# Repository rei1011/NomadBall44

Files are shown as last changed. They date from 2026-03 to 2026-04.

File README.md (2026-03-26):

# NomadBall44

## ライセンス

本リポジトリのオリジナル部分は **GNU General Public License v3**（[LICENSE](LICENSE)）です。

## 第三者ソフトウェア・素材

キーボード設計にあたり、以下のオープンソース／クリエイティブ・コモンズの成果物を利用しています。帰属表示、MIT 全文、GPLv3 との関係、CC BY-SA の条項へのリンクは **[NOTICES](NOTICES)** にまとめています。上流ライセンスのコピーは **[third_party/](third_party/)** にも置いています。

| 名称 | 参照 |
|---|---|
| Salicylic-acid3 / KiCAD_FootPrint（MIT） | https://github.com/Salicylic-acid3/KiCAD_FootPrint |
| koktoh / BrownSugar_KBD_KiCad_Library（MIT） | https://github.com/koktoh/BrownSugar_KBD_KiCad_Library |
| kumamuk-git / roBa（GPL-3.0） | https://github.com/kumamuk-git/roBa |
| Seeed Studio / OPL_Kicad_Library（CC BY-SA 4.0） | https://github.com/Seeed-Studio/OPL_Kicad_Library |

Seeed OPL 由来の KiCad シンボル・フットプリントのファイル一覧、改変内容の説明、および派生ファイルを単体で再配布する際の表示の目安は、**[NOTICES](NOTICES)** のセクション 4 に記載しています。

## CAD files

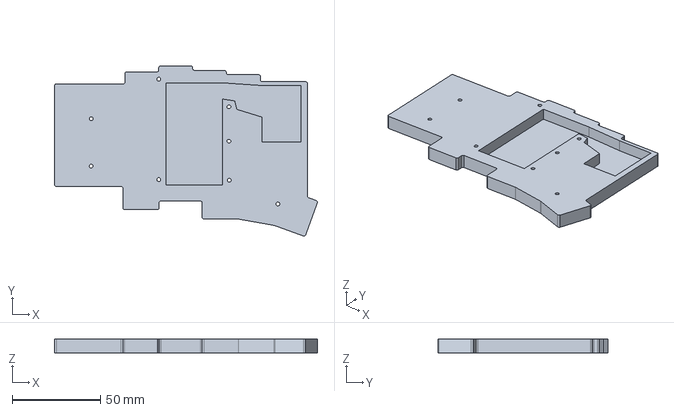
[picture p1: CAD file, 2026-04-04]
design_data/NomadBall44_L_Bottom_v2/freecad/NomadBall44_L_Bottom_v2.FCStd
149.0 x 96.5 x 7.70 mm

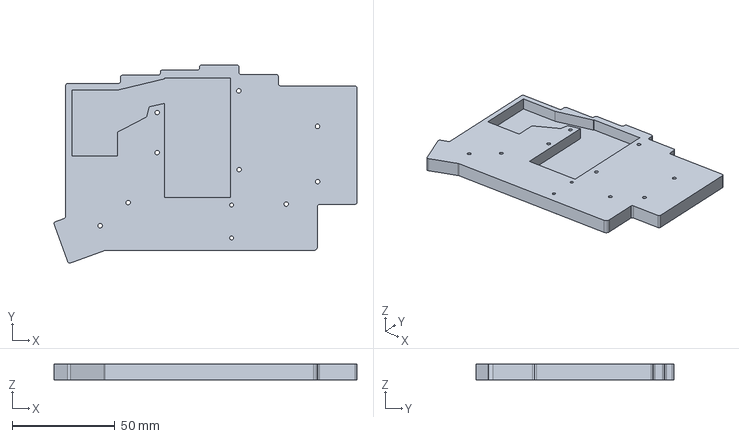
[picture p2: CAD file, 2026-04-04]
design_data/NomadBall44_R_Bottom_v2/freecad/NomadBall44_R_Bottom_v2.FCStd
147.4 x 96.5 x 7.70 mm

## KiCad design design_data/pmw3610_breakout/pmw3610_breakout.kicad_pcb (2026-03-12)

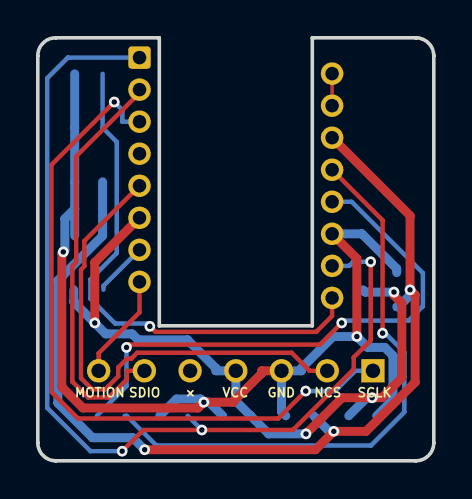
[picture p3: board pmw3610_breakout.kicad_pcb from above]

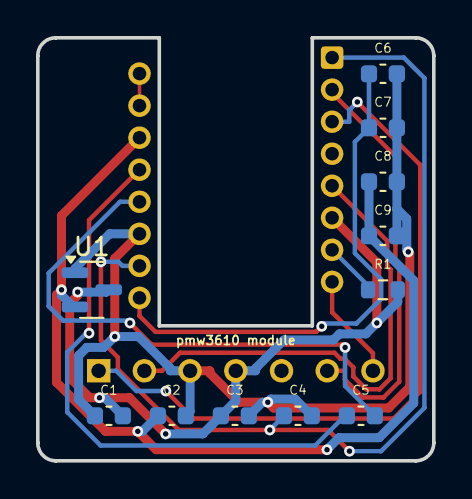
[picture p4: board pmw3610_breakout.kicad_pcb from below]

Board: 2 copper layers, 22.0 x 23.5 mm, 13 parts (11 on the bottom side), 13 nets.

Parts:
C1, C2: 1u; C_0603_1608Metric
C3, C5, C8: 100n; C_0603_1608Metric
C4, C7: 10n; C_0603_1608Metric
C6: 10u (X7R); C_0603_1608Metric
C9: 3.3u/25V; C_0603_1608Metric
J1: Conn_01x08; pmw3610_connector_b
R1: 10k; R_0603_1608Metric
U1: MCP1700T-1802E/TT; SOT-23
U2: PMW3610; PMW3610DM-SUDU 16Pin

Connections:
+1V9: C2.1, C8.1, C9.1, U1.2 (VO), U2.14 (VDD)
GND: C1.1, C2.2, C3.2, C4.2, C6.2, C7.2, C8.2, C9.2, J1.3, U1.1 (GND), U2.11 (GND)
MOTION: J1.7 (Pin_6), U2.8 (MOTION)
NCS: J1.2, U2.5 (NCS)
unnamed: C4.1, U2.1 (+VCSEL), U2.10 (PASS_T)
unnamed: U2.15 (XYLASER), U2.16 (-VCSEL)
unnamed: C5.1, U2.13 (CN)
unnamed: C5.2, U2.12 (CP)
unnamed: R1.1, U2.7 (NRESET)
unnamed: C6.1, C7.1, U2.9 (VCP)
SCLK: J1.1, U2.3 (SCLK)
SDIO: J1.6, U2.2 (SDIO)
VCC: C1.2, C3.1, J1.4, R1.2, U1.3 (VI), U2.6 (VDDIO)

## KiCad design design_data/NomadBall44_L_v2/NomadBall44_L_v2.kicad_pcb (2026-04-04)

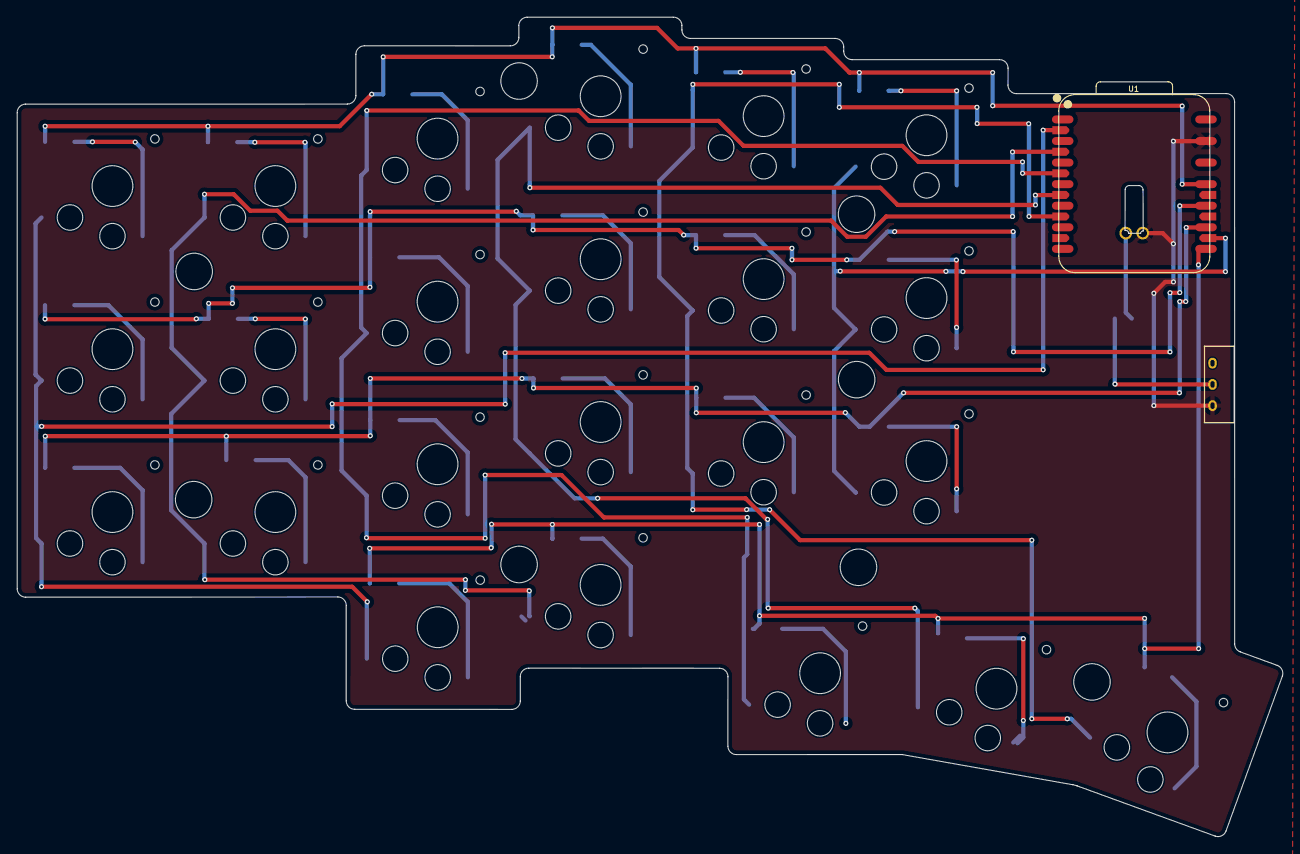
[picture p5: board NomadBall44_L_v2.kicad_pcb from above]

Board: 2 copper layers, 149.0 x 96.5 mm, 49 parts (1 on the bottom side), 36 nets.

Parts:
BT1: Battery_Cell; JST_S2B-PH-SM4-TB
D1, D2, D3, D4, D5, D6, D7, D8, D9, D10, D11, D12, D13, D14, D15, D16, D17, D18, D19, D20, D21, D22, D23: D; Diode_SMD
SW1, SW2, SW3, SW4, SW5, SW6, SW7, SW8, SW9, SW10, SW11, SW12, SW13, SW14, SW15, SW16, SW17, SW18, SW19, SW20, SW21, SW22, SW23: SW_Push; Choc_v2_Hotswap_1u
SW24: SW_SPDT; TGSW_MSK-12D19
U1: XIAO-nRF52840-Plus-SMD; XIAO-nRF52840-Plus-ver3

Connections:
Bat: BT1.1 (+), U1.32 (VBAT)
Col0: SW1.1, SW7.1, SW13.1, SW19.1, U1.15 (P0.15_D11_I2S_SD)
Col1: SW2.1, SW8.1, SW14.1, SW20.1, U1.16 (P0.19_D12_I2S_SCK)
Col2: SW3.1, SW9.1, SW15.1, SW21.1, U1.17 (P1.01_D13_I2S_WS)
Col3: SW4.1, SW10.1, SW16.1, SW22.1, U1.18 (P0.09_D14_NFC1_RX1)
Col4: SW5.1, SW11.1, SW17.1, SW23.1, U1.19 (P0.10_D15_NFC2_TX1)
Col5: SW6.1, SW12.1, SW18.1, U1.21 (P1.03_D17_SCK1)
GND: SW24.3 (C), U1.13 (GND), U1.33 (GND)
unnamed: BT1.2 (-), SW24.2 (B)
unnamed: D1.2 (A), SW1.2
unnamed: D2.2 (A), SW2.2
unnamed: D3.2 (A), SW3.2
unnamed: D4.2 (A), SW4.2
unnamed: D5.2 (A), SW5.2
unnamed: D6.2 (A), SW6.2
unnamed: D7.2 (A), SW7.2
unnamed: D8.2 (A), SW8.2
unnamed: D9.2 (A), SW9.2
unnamed: D10.2 (A), SW10.2
unnamed: D11.2 (A), SW11.2
unnamed: D12.2 (A), SW12.2
unnamed: D13.2 (A), SW13.2
unnamed: D14.2 (A), SW14.2
unnamed: D15.2 (A), SW15.2
unnamed: D16.2 (A), SW16.2
unnamed: D17.2 (A), SW17.2
unnamed: D18.2 (A), SW18.2
unnamed: D19.2 (A), SW19.2
unnamed: D20.2 (A), SW20.2
unnamed: D21.2 (A), SW21.2
unnamed: D22.2 (A), SW22.2
unnamed: D23.2 (A), SW23.2
Row0: D1.1 (K), D2.1 (K), D3.1 (K), D4.1 (K), D5.1 (K), D6.1 (K), U1.11 (P1.15_D10_MOSI)
Row1: D7.1 (K), D8.1 (K), D9.1 (K), D10.1 (K), D11.1 (K), D12.1 (K), U1.10 (P1.14_D9_MISO)
Row2: D13.1 (K), D14.1 (K), D15.1 (K), D16.1 (K), D17.1 (K), D18.1 (K), U1.9 (P1.13_D8_SCK)
Row3: D19.1 (K), D20.1 (K), D21.1 (K), D22.1 (K), D23.1 (K), U1.8 (P1.12_D7_RX)

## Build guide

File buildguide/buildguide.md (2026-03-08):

# ダイオードはんだ付け
- 部品
  - ダイオード
- 手順
  - PCB基板裏面へダイオードを取り付ける

# キーソケットはんだ付け
- 部品
  - キースケット
- 手順
  - PCB基板裏面へキーソケットを取り付ける
    - 親指キーはchoc v1、choc v2を取り付ける

# マイコン関連のはんだ付け
- 部品
  - マイコン
  - PHコネクタ
  - スライドスイッチ
- 手順
  - PCB基板表面へマイコンを取り付ける
    - バッテリー用ピンは裏面からはんだ付けを行う
  - PCB基板裏面へPHコネクタを取り付ける
  - PCB基板表面へ水平スライドスイッチを取り付ける

# ロータリーエンコーダーはんだ付け
- 部品
  - ロータリーエンコーダー
  - ノブ
- 手順
  - PCB基板表面へロータリーエンコーダーを取り付ける
  
# トラックボールはんだ付け
- 部品
  - L字コンスルー
  - 読み取り用基板
  - 読み取り用センサ
  - 読み取り用レンズ
  - トラックボールケース
  - トラックボール
- 手順
  - PCB基板表面へL字コンスルーを取り付ける
    - 直線ピンを基板側へ差し込みはんだ付け
  - PMW3610をトラックボール読み取り基盤裏面へ取り付ける
  - レンズをはめる

# トップ/ボトムプレートの取り付け
# キースイッチ取り付け
# バッテリー取り付け
# firmwareへの書き込み

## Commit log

2026-03-03 右側の電子回路図を作成
    [NomadBall44_R.kicad_pcb, NomadBall44_R.kicad_sch]
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2026-03-06 トラックボール基板発注ようにIC部品を割り当て
    [NomadBall44_R.kicad_sch, pmw3610_breakout.kicad_pcb, pmw3610_breakout.kicad_sch]
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2026-03-06 抵抗が大きすぎたので修正
    [pmw3610_breakout.kicad_pcb, pmw3610_breakout.kicad_sch]
2026-03-06 ロータリエンコーダーのフットプリントを割り当て
    [NomadBall44_R.kicad_sch]
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2026-03-07 NomadBall44用のシンボルライブラリを作成
    [NomadBall44_R.kicad_sch]
2026-03-07 pmw3610のコネクター用フットプリントを追加
    [NomadBall44_R.kicad_sch]
2026-03-07 シンボルとフットプリントのライブラリのパスを修正
    [NomadBall44_R.kicad_sch]
2026-03-07 キースイッチのシンボルにフットプリントを割り当て
    [NomadBall44_R.kicad_sch]
2026-03-07 水平スライドスイッチのフットプリントを追加
    [NomadBall44_R.kicad_pcb, NomadBall44_R.kicad_sch]
2026-03-07 デバッグするためにリファレンスフィールドを表示するようにした
    [NomadBall44_R.kicad_sch]
2026-03-07 キースイッチのフットプリントを配置
    [NomadBall44_R.kicad_pcb]
2026-03-07 キーソケットの位置を微調整
    [NomadBall44_R.kicad_pcb]
2026-03-07 pmw3610のコネクタの位置を微調整
    [NomadBall44_R.kicad_pcb]
2026-03-07 スライドスイッチとロータリーエンコーダーの位置を微修正
    [NomadBall44_R.kicad_pcb]
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2026-03-08 スペーサーを追加
    [NomadBall44_R.kicad_pcb]
2026-03-08 水平スライドスイッチの位置を修正
    [NomadBall44_R.kicad_pcb]
2026-03-08 スペーサーの位置を修正
    [NomadBall44_R.kicad_pcb]
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2026-03-08 スペーサー用のホール位置を修正
    [NomadBall44_R.kicad_pcb]
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2026-03-09 ボトムプレート用のkicadファイルを作成
    [NomadBall44_R_Bottom.kicad_pcb, NomadBall44_R_Bottom.kicad_sch, NomadBall44_R_Bottom.step]
2026-03-09 外形線にノイズが入っていたので除去
    [NomadBall44_R_Bottom.kicad_pcb]
2026-03-09 外形線を微修正
    [NomadBall44_R.kicad_pcb]
2026-03-10 ボトムプレートの作成
    [NomadBall44_R_Bottom.kicad_pcb, NomadBall44_R_Bottom.step]
2026-03-10 トッププレートのネジ穴とスイッチ穴を設定
    [NomadBall44_R_Top.kicad_pcb, NomadBall44_R_Top.kicad_sch]
2026-03-10 トッププレート用のkicad projectを作成
    [NomadBall44_R_Top.kicad_pcb]
2026-03-10 ロータリーエンコーダーの位置を微修正
    [NomadBall44_R.kicad_pcb]
2026-03-10 トッププレートからダイオードのフットプリントを削除
    [NomadBall44_R_Top.kicad_pcb]
2026-03-10 PCB基盤の外形線を修正
    [NomadBall44_R.kicad_pcb]
2026-03-10 トラックボール用の配線を追加 & 端面スルーホール向けに導体から基板端のクリアランスを0に設定
    [NomadBall44_R.kicad_pcb]
2026-03-10 トラックボールとバッテリー周りを配線
    [NomadBall44_R.kicad_pcb]
2026-03-10 マイコンまわりの配線が完了 & ラベルの間違えを修正
    [NomadBall44_R.kicad_pcb, NomadBall44_R.kicad_sch]
2026-03-10 キースイッチまわりの配線完了
    [NomadBall44_R.kicad_pcb]
2026-03-11 不要なファイルを削除
    [NomadBall44_R_Bottom.kicad_pcb, NomadBall44_R_Bottom.kicad_sch, NomadBall44_R_Top.kicad_pcb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]
2026-03-11 トッププレート用のkicadプロジェクトを作成
    [NomadBall44_R_Top.kicad_pcb, NomadBall44_R_Top.kicad_sch]
2026-03-11 スイッチホールとネジ用ホールを設定
    [NomadBall44_R_Top.kicad_pcb]
2026-03-11 ダイオードを削除
    [NomadBall44_R_Top.kicad_pcb]
2026-03-11 配線を削除
    [NomadBall44_R_Top.kicad_pcb]
2026-03-11 トッププレートに不要なエリアを削除
    [NomadBall44_R.kicad_pcb, NomadBall44_R_Top.kicad_pcb]
2026-03-11 親指用トッププレート用のプロジェクトを作成
    [NomadBall44_R_Top_Thumb.kicad_pcb, NomadBall44_R_Top_Thumb.kicad_sch]
2026-03-11 ダイオードの削除 & キーホールとネジ用ホールを設定
    [NomadBall44_R_Top_Thumb.kicad_pcb]
2026-03-11 親指用の外形線を作成
    [NomadBall44_R_Top_Thumb.kicad_pcb]
2026-03-11 ボトムプレート用の外形線を削除
    [NomadBall44_R_Bottom.kicad_pcb, NomadBall44_R_Bottom.kicad_sch]
2026-03-11 ダイオードとキースイッチのフットプリントを削除
    [NomadBall44_R_Bottom.kicad_pcb]
2026-03-11 ネジ用ホールを設定
    [NomadBall44_R_Bottom.kicad_pcb]
2026-03-11 不要な配線を削除
    [NomadBall44_R_Bottom.kicad_pcb]
2026-03-11 PHコネクタとバッテリー用のエリアを作成
    [NomadBall44_R_Bottom.kicad_pcb]
2026-03-11 ネジ穴を一つ追加
    [NomadBall44_R.kicad_pcb, NomadBall44_R_Bottom.kicad_pcb, NomadBall44_R_Top.kicad_pcb]
2026-03-11 keyballのボトムケースデータを読み込み
    [NomadBall44_R_Bottom.kicad_pcb]
2026-03-11 m1.9用のネジ穴を追加 & PHコネクタ用のエリアを修正
    [NomadBall44_R_Bottom.kicad_pcb]
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2026-03-11 左手PCB基板用のプロジェクトを作成
    [NomadBall44_L.kicad_pcb, NomadBall44_L.kicad_sch]
2026-03-11 左手用の回路図を作成
    [NomadBall44_L.kicad_sch]
2026-03-11 フットプリントの割り当てを更新
    [NomadBall44_L.kicad_sch]
2026-03-11 PCB基盤のガーバファイルを生成
    [NomadBall44_L.kicad_pcb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]
2026-03-11 ボトムプレートのガーバファイルを生成
    [NomadBall44_R_Bottom.kicad_pcb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]
2026-03-11 トッププレートのガーバファイルを生成
    [NomadBall44_R_Top-B_Cu.gbr, NomadBall44_R_Top-B_Mask.gbr, NomadBall44_R_Top-B_Silkscreen.gbr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]
2026-03-11 トッププレート（親指）のガーバファイルを生成
    [NomadBall44_R_Top_Thumb-B_Cu.gbr, NomadBall44_R_Top_Thumb-B_Mask.gbr, NomadBall44_R_Top_Thumb-B_Silkscreen.gbr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]
2026-03-11 左手キーボードのフットプリントをインポート
    [NomadBall44_L.kicad_pcb]
2026-03-11 右側PCBのレイアウトを反転さ左側PCBに配置
    [NomadBall44_L.kicad_pcb]
2026-03-11 キースイッチを一部配置
    [NomadBall44_L.kicad_pcb]
2026-03-11 外形線とスペーサーの位置を修正
    [NomadBall44_L.kicad_pcb]
2026-03-11 PHコネクタを反転
    [NomadBall44_L.kicad_pcb]
2026-03-12 ダイオードを配置
    [NomadBall44_L.kicad_pcb]
2026-03-12 マイコン周りのフットプリントを配置
    [NomadBall44_L.kicad_pcb]
2026-03-12 バッテリー周りの配線を修正
    [NomadBall44_R.kicad_pcb]
2026-03-12 マイコン周りの配線を実施
    [NomadBall44_L.kicad_pcb]
2026-03-12 キースイッチの配線が完了
    [NomadBall44_L.kicad_pcb]
2026-03-12 PCB基板発注用のファイルを生成
    [NomadBall44_L-B_Cu.gbr, NomadBall44_L-B_Mask.gbr, NomadBall44_L-B_Silkscreen.gbr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]
2026-03-12 トッププレート用のプロジェクトを作成
    [NomadBall44_L_Top-B_Cu.gbr, NomadBall44_L_Top-B_Mask.gbr, NomadBall44_L_Top-B_Silkscreen.gbr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]
2026-03-12 トッププレート完成
    [NomadBall44_L_Top.kicad_pcb]
2026-03-12 トッププレート（親指）の作成
    [NomadBall44_L_Top_Thumb.kicad_pcb, NomadBall44_L_Top_Thumb.kicad_sch]
2026-03-12 ボトムプレートのプロジェクトを作成
    [NomadBall44_L_Bottom.kicad_pcb, NomadBall44_L_Bottom.kicad_sch]
2026-03-12 ボトムプレートを作成
    [NomadBall44_L_Bottom.kicad_pcb]
2026-03-12 トッププレートのガーバファイルとドリルファイルを生成
    [NomadBall44_L_Top-B_Cu.gbr, NomadBall44_L_Top-B_Mask.gbr, NomadBall44_L_Top-B_Silkscreen.gbr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]
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2026-03-12 ボトムプレートの位置を修正
    [NomadBall44_L_Bottom.kicad_pcb]
2026-03-12 ボトムプレートのガーバファイルとドリルファイルを修正
    [NomadBall44_L_Bottom-B_Cu.gbr, NomadBall44_L_Bottom-B_Mask.gbr, NomadBall44_L_Bottom-B_Silkscreen.gbr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]
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2026-03-12 抵抗値を微修正
    [pmw3610_breakout.kicad_pcb]
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2026-03-13 発注用のデータをgit管理から除外 & ディレクトリ名を修正
    [NomadBall44_L-B_Cu.gbr, NomadBall44_L-B_Mask.gbr, NomadBall44_L-B_Silkscreen.gbr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]
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2026-03-14 refactor: KiCad関連ディレクトリを design_data/ へ移行
    - lib, NomadBall44_L, NomadBall44_L_Bottom, NomadBall44_L_Top
    - NomadBall44_L_Top_Thumb, NomadBall44_R, NomadBall44_R_Bottom
    - NomadBall44_R_Top, NomadBall44_R_Top_Thumb, pmw3610_breakout
    を design_data/ 配下に移動
    Made-with: Cursor
    [NomadBall44_L.kicad_pcb, NomadBall44_L.kicad_sch, NomadBall44_L_Bottom.kicad_pcb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]
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2026-04-01 nrf52840 plusのfootprintを変更し配線を修正
    [NomadBall44_R_v2.kicad_pcb]
2026-04-01 右手基板のシンボルとフットプリントの紐付けを修正
    [NomadBall44_R_v2.kicad_sch]
2026-04-01 左手基板のマイコンfootprintを変更し配線を修正
    [NomadBall44_L_v2.kicad_pcb]
2026-04-01 DRCで発生したエラーを修正
    [NomadBall44_R_v2.kicad_pcb]
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2026-04-01 キースイッチの配置を修正
    [NomadBall44_L_v2.kicad_pcb]
2026-04-01 ダイオードの配置を修正
    [NomadBall44_L_v2.kicad_pcb]
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2026-04-01 シンボルとフットプリントの紐付けを修正
    [NomadBall44_L_v2.kicad_sch]
2026-04-02 左手基板のキー位置を修正
    [NomadBall44_L_v2.kicad_pcb]
2026-04-02 BAT用の配線を微修正
    [NomadBall44_L_v2.kicad_pcb]
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2026-04-02 スペーサーの位置を微修正
    [NomadBall44_L_v2.kicad_pcb]
2026-04-02 DRCのエラーを修正
    [NomadBall44_L_v2.kicad_pcb]
2026-04-02 スイッチ番号の表記位置を修正
    [NomadBall44_L_v2.kicad_pcb]
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2026-04-03 薄い箇所が0.8mm（jlpcbの制限値）以下になっていたので修正
    [NomadBall44_R_Bottom_v2.FCStd]
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2026-04-04 ポケットを微修正
    [NomadBall44_L_Bottom_v2.FCStd]
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2026-04-04 トッププレートの外形線を微修正
    [NomadBall44_L_Top_Thumb_v2.kicad_pcb]
